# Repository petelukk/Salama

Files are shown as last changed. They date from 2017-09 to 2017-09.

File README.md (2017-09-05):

# Salama
Sikin led salamaan ja Otit led merkkiin koodi, piirilevy ja ohjeet

## Piirilevyt
Piirretty Kicadilla.
Todo: Syövytystä varten maskit. Sik maski saattaa löytyä vielä jostain. Otitille ei ole tehty vaan levyt jyrsittiin.

### Piirilevyn kasausohje
TODO Pittää ettiä jostain...

## Ohjelma

Ohjelma siirtyy levylle kätevästi käyttäen arduinoa ohjelmointilaitteena.

```
Salaman ohjelmointiliittimen pinnit keskeltä reunalle:

Nro:  Nimi:   Arduinon pinni (nano):

6:    Reset   10
5:    GND     GND
4:    VCC     VCC
3:    SCK     13
2:    MISO    12
1:    MOSI    11

Muista vetää arduinon Reset ylös. Ardu nollautuu kun sarjaliikenne alotetaan....
```

Src hakemistossa on lediportit_oikein.h ja lediportit_väärin.h tiedostot joista jompikumpi kopioidaan lediportit.h tiedoston päälle mikäli ledit on juotettu vastoin ohjetta. (TODO: nimet ovat ehkä väärin)

Koodin kääntämiseen ja ohjelman levylle siirtämiseen komennot ovat:
```
// kääntäminen
avr-gcc -mmcu=attiny861 vilkutus.c salama.c -I./ -Os -DF_CPU=8000000UL  

// Fläsäys käyttäen arduino-isp:tä
avrdude -c avrisp -p t861 -B3 -P /dev/ttyUSB0 -b 19200 -U flash:w:a.out

// Fuse asetukset käyttäen arduino-isp:tä
avrdude -c avrisp -p t861 -B3 -P /dev/ttyUSB0 -b 19200 -U lfuse:w:0xe2:m -U hfuse:w:0xdf:m
```

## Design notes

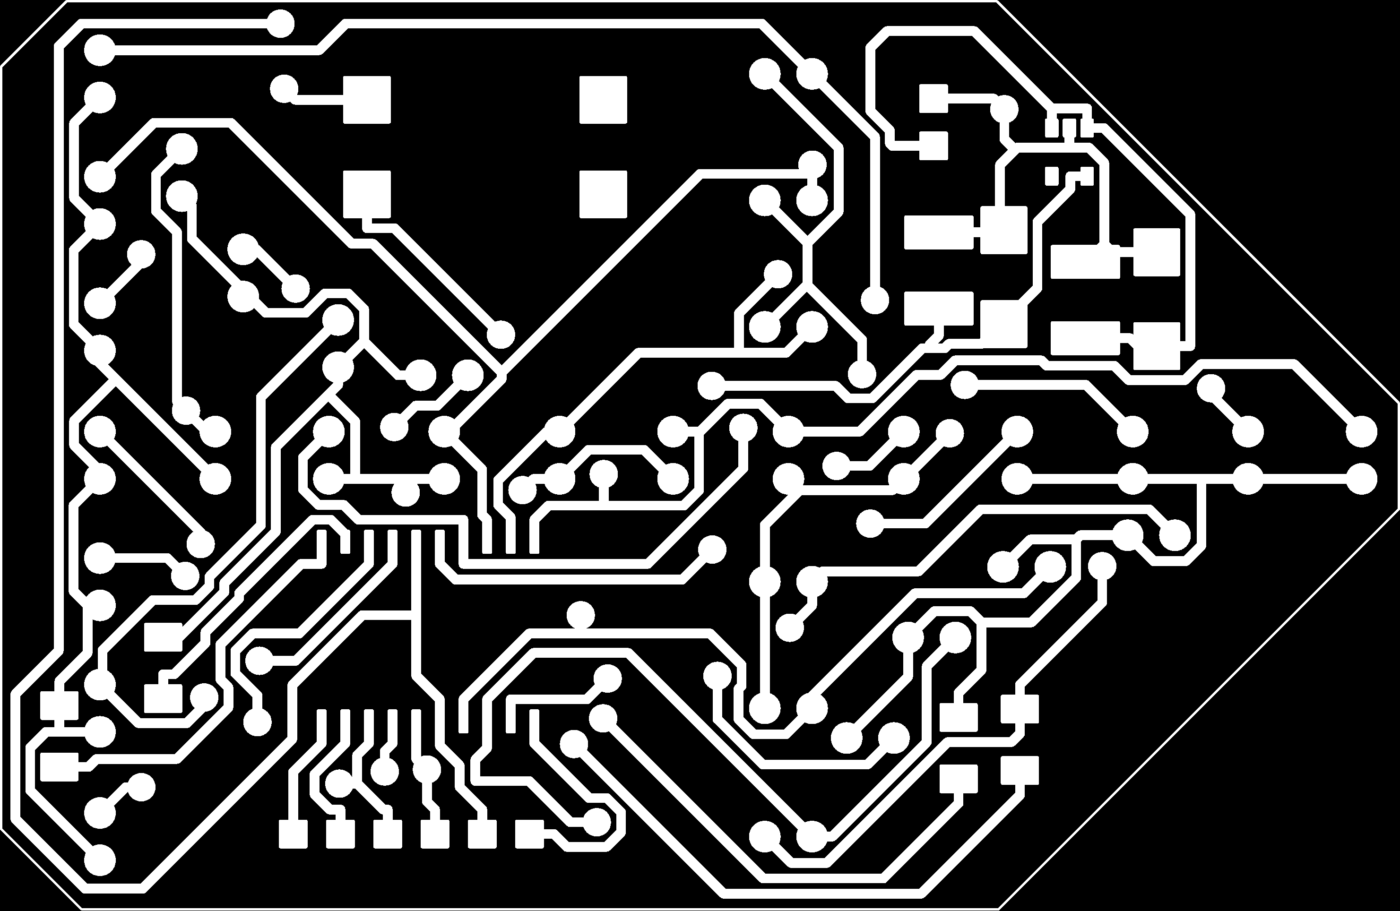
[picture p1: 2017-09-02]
gerberit/png/etu.png

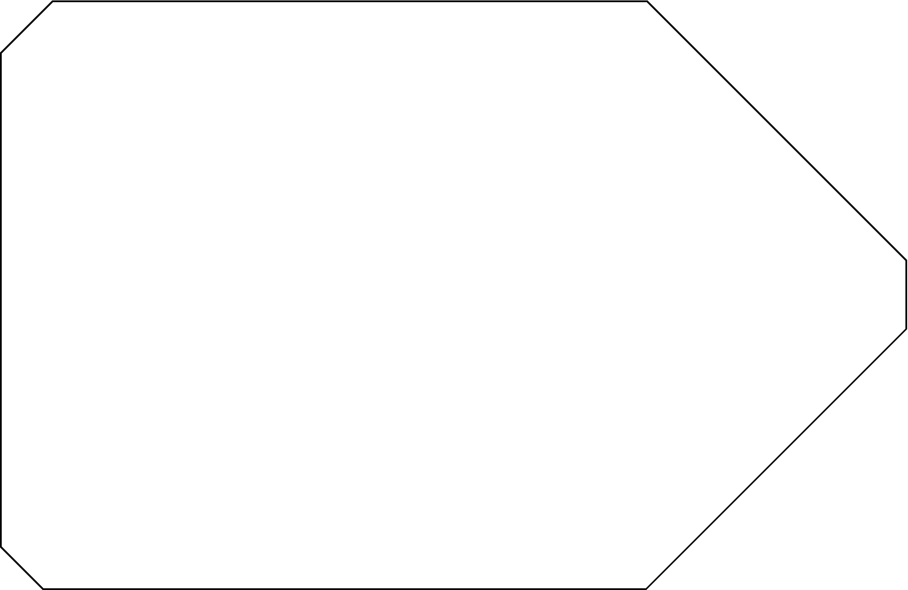
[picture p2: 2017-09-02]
gerberit/png/edge.png

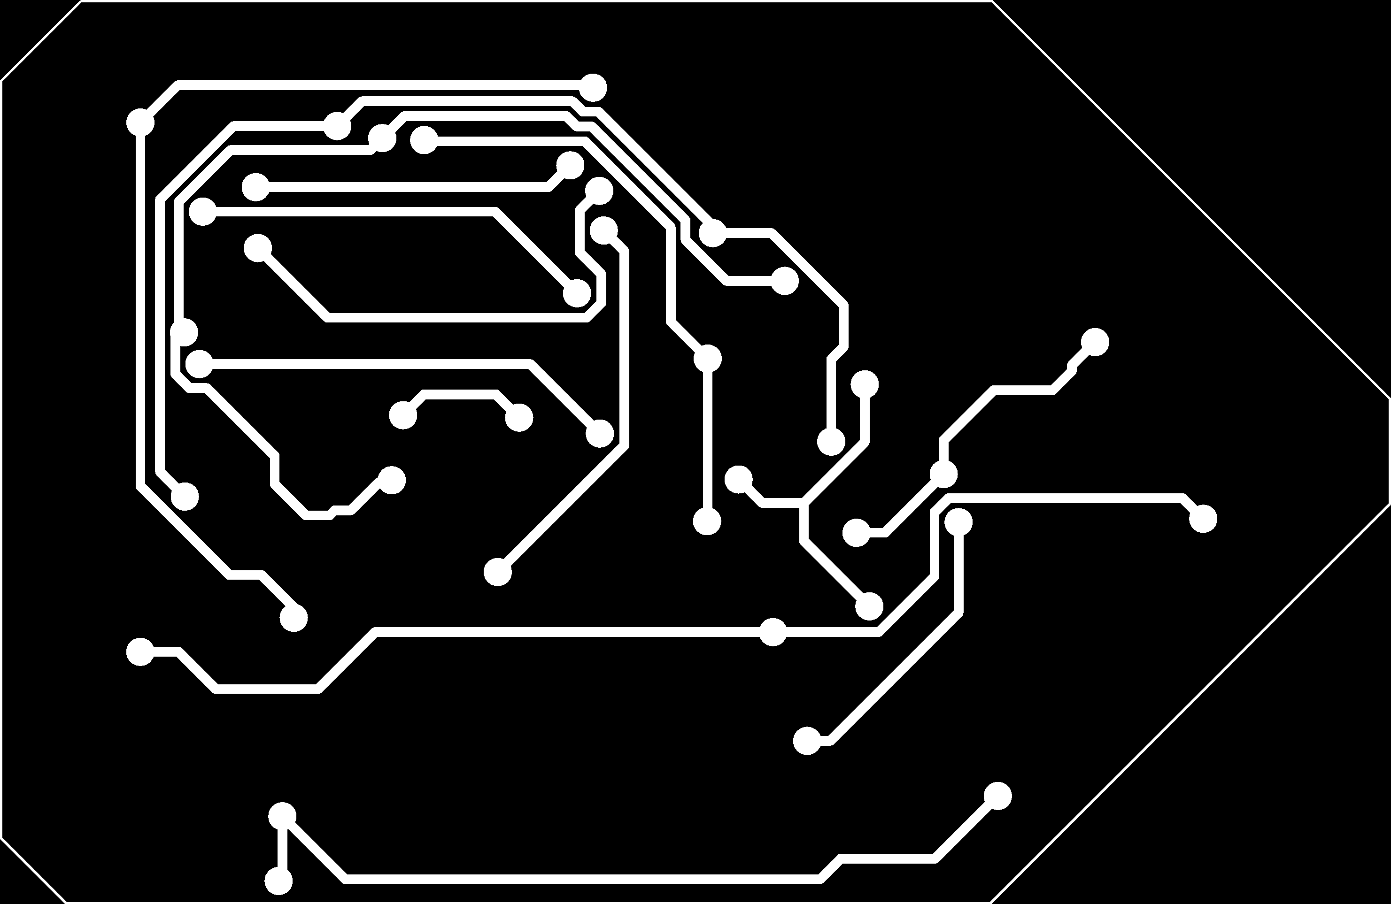
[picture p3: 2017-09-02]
gerberit/png/taka.png

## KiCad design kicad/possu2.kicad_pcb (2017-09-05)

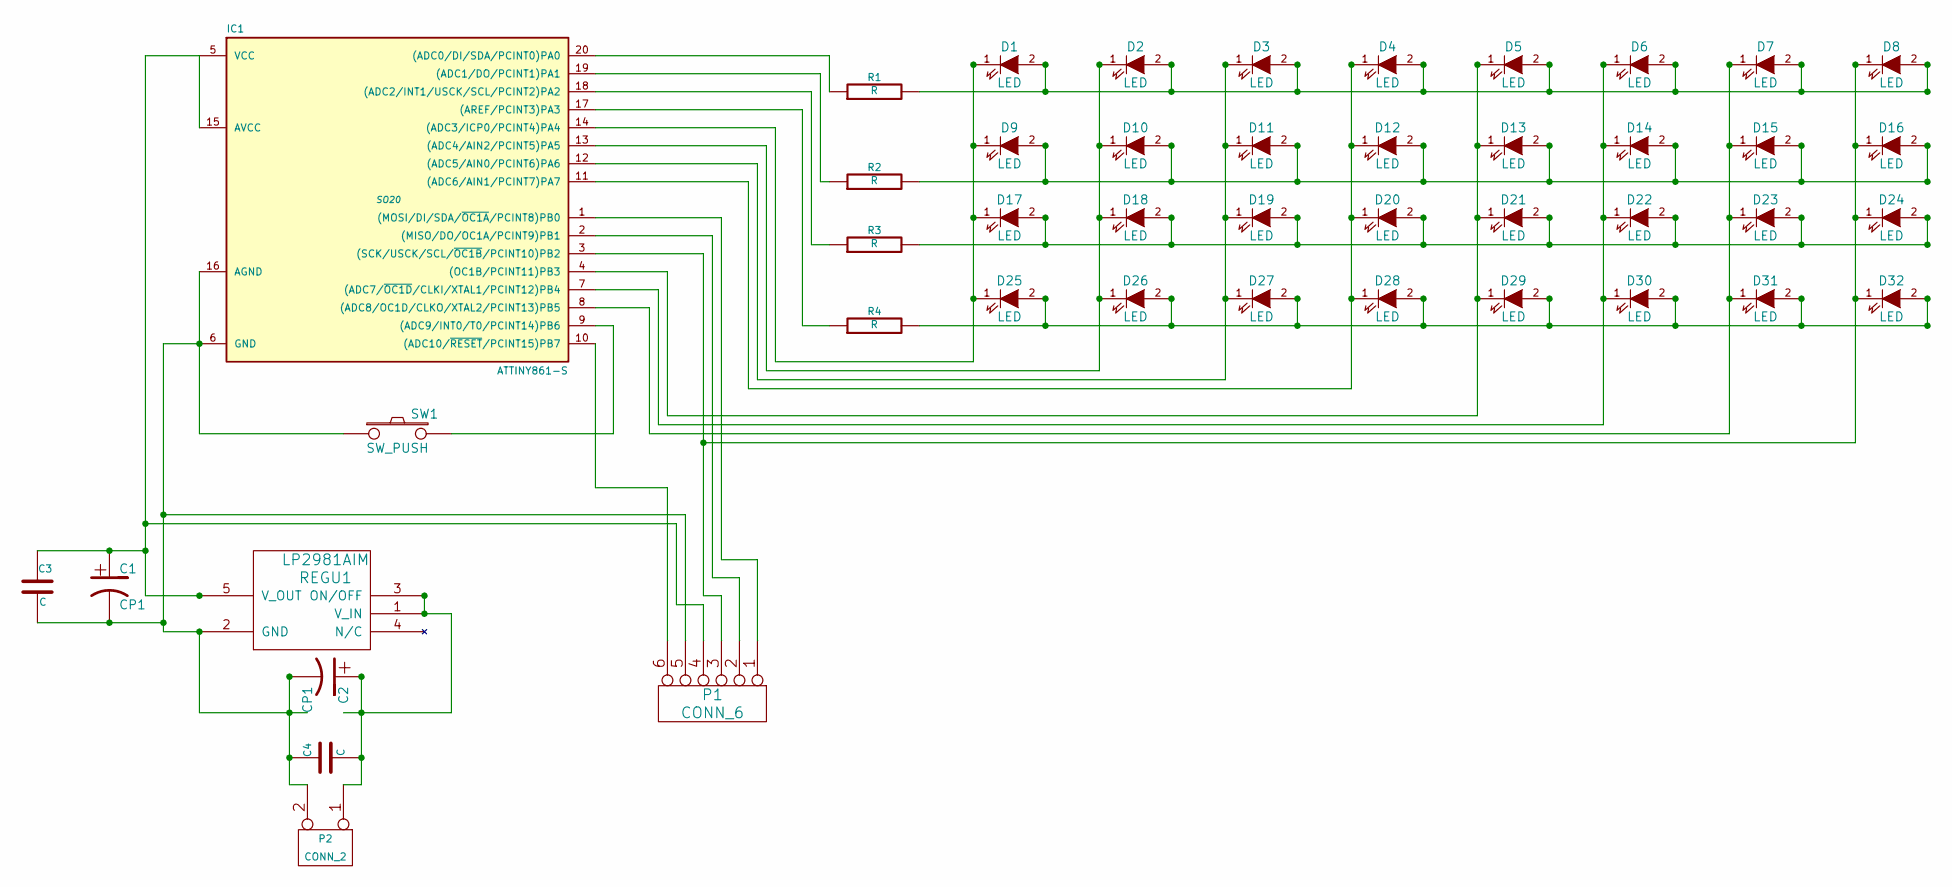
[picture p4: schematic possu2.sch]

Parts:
C1, C2: CP1
C3, C4: C
D1, D2, D3, D4, D5, D6, D7, D8, D9, D10, D11, D12, D13, D14, D15, D16, D17, D18, D19, D20, D21, D22, D23, D24, D25, D26, D27, D28, D29, D30, D31, D32: LED
IC1: ATTINY861-S; SO20
P1: CONN_6
P2: CONN_2
R1, R2, R3, R4: R
REGU1: LP2981AIM
SW1: SW_PUSH

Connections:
unnamed: IC1.18 ((ADC2/INT1/USCK/SCL/PCINT2)PA2), R3.1
unnamed: IC1.19 ((ADC1/DO/PCINT1)PA1), R2.1
unnamed: IC1.20 ((ADC0/DI/SDA/PCINT0)PA0), R1.1
unnamed: IC1.2 ((MISO/DO/OC1A/PCINT9)PB1), P1.2
unnamed: IC1.10 ((ADC10/~RESET~/PCINT15)PB7), P1.6
unnamed: IC1.9 ((ADC9/INT0/T0/PCINT14)PB6), SW1.2
unnamed: IC1.1 ((MOSI/DI/SDA/~OC1A~/PCINT8)PB0), P1.1
unnamed: IC1.17 ((AREF/PCINT3)PA3), R4.1
unnamed: D1.1 (K), D9.1 (K), D17.1 (K), D25.1 (K), IC1.14 ((ADC3/ICP0/PCINT4)PA4)
unnamed: D2.1 (K), D10.1 (K), D18.1 (K), D26.1 (K), IC1.13 ((ADC4/AIN2/PCINT5)PA5)
unnamed: D6.1 (K), D14.1 (K), D22.1 (K), D30.1 (K), IC1.7 ((ADC7/~OC1D~/CLKI/XTAL1/PCINT12)PB4)
unnamed: D7.1 (K), D15.1 (K), D23.1 (K), D31.1 (K), IC1.8 ((ADC8/OC1D/CLKO/XTAL2/PCINT13)PB5)
unnamed: D8.1 (K), D16.1 (K), D24.1 (K), D32.1 (K), IC1.3 ((SCK/USCK/SCL/~OC1B~/PCINT10)PB2), P1.3
unnamed: D3.1 (K), D11.1 (K), D19.1 (K), D27.1 (K), IC1.12 ((ADC5/AIN0/PCINT6)PA6)
unnamed: D4.1 (K), D12.1 (K), D20.1 (K), D28.1 (K), IC1.11 ((ADC6/AIN1/PCINT7)PA7)
unnamed: D5.1 (K), D13.1 (K), D21.1 (K), D29.1 (K), IC1.4 ((OC1B/PCINT11)PB3)
unnamed: D9.2 (A), D10.2 (A), D11.2 (A), D12.2 (A), D13.2 (A), D14.2 (A), D15.2 (A), D16.2 (A), R2.2
unnamed: C1.1, C3.1, IC1.5 (VCC), IC1.15 (AVCC), P1.4, REGU1.5 (V_OUT)
unnamed: D25.2 (A), D26.2 (A), D27.2 (A), D28.2 (A), D29.2 (A), D30.2 (A), D31.2 (A), D32.2 (A), R4.2
unnamed: D17.2 (A), D18.2 (A), D19.2 (A), D20.2 (A), D21.2 (A), D22.2 (A), D23.2 (A), D24.2 (A), R3.2
unnamed: D1.2 (A), D2.2 (A), D3.2 (A), D4.2 (A), D5.2 (A), D6.2 (A), D7.2 (A), D8.2 (A), R1.2
unnamed: C2.1, C4.2, P2.1, REGU1.1 (V_IN), REGU1.3 (ON/OFF)
unnamed: C1.2, C2.2, C3.2, C4.1, IC1.6 (GND), IC1.16 (AGND), P1.5, P2.2 (PM), REGU1.2 (GND), SW1.1

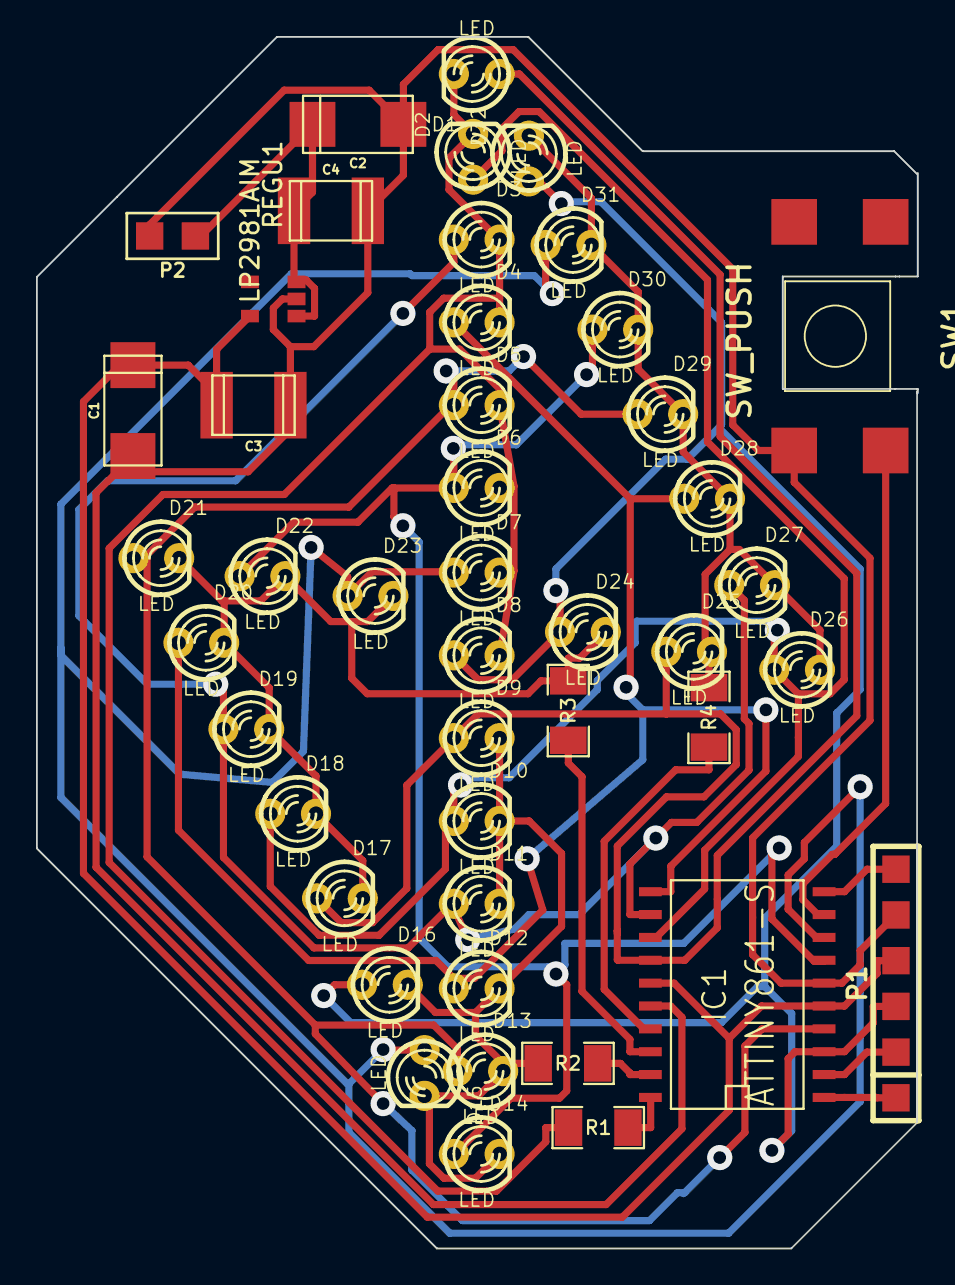
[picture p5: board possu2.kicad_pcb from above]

Board: 2 copper layers, 48.9 x 67.3 mm, 45 parts (0 on the bottom side), 23 nets.

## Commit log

2017-09-02 Filuja siivoiltu
    [otit.dsn, otit.kicad_pcb, otit.sch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]
2017-09-05 Piirsin salamaan edgecutsit ja tein valmistusgerberit jotta voidaan tilata
    [possu2.kicad_pcb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]
